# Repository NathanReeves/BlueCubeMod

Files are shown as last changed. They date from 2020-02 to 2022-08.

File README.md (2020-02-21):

# BlueCubeMod

ESP32 based GameCube Controller Bluetooth conversion for Nintendo Switch

v1:
Mac/PC/PS4 supported (tested using Dolphin Emulator on Mac, for Switch/RaspberryPi, use an 8Bitdo USB adapter)

v2: 
Switch support only - no adapter required

## Wiring:

- Connect pins 23 and 18 to GameCube controller's data pin (Red)

- Connect GND to controller's ground pin (Black)

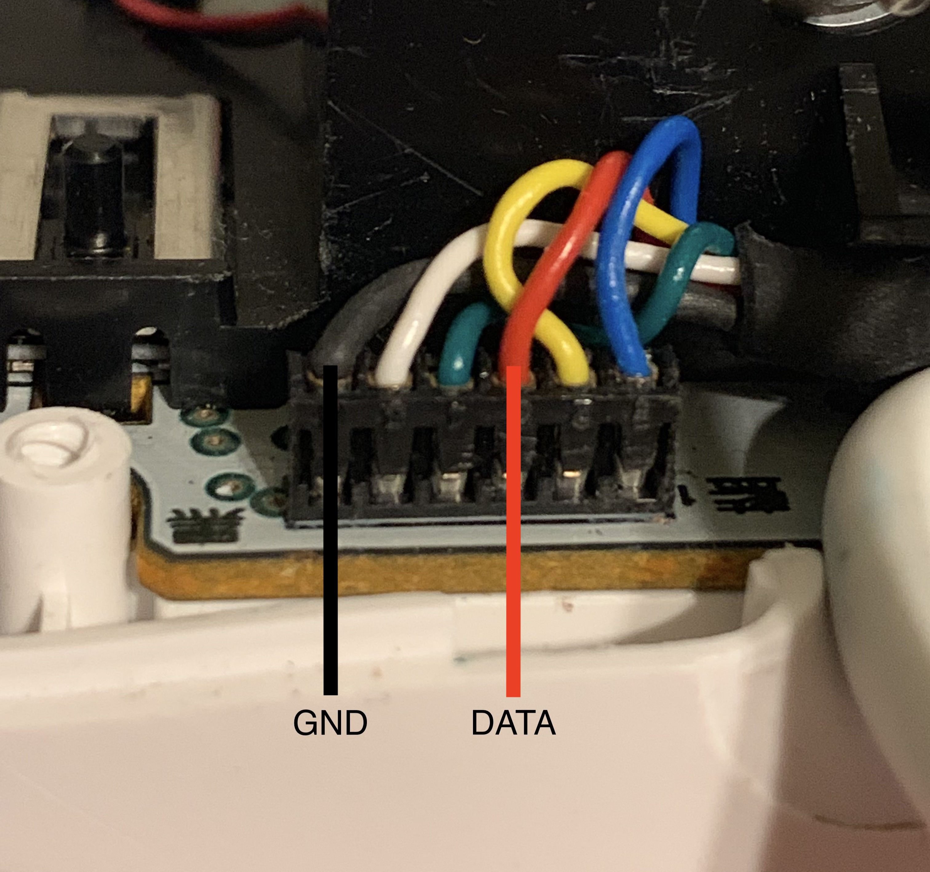
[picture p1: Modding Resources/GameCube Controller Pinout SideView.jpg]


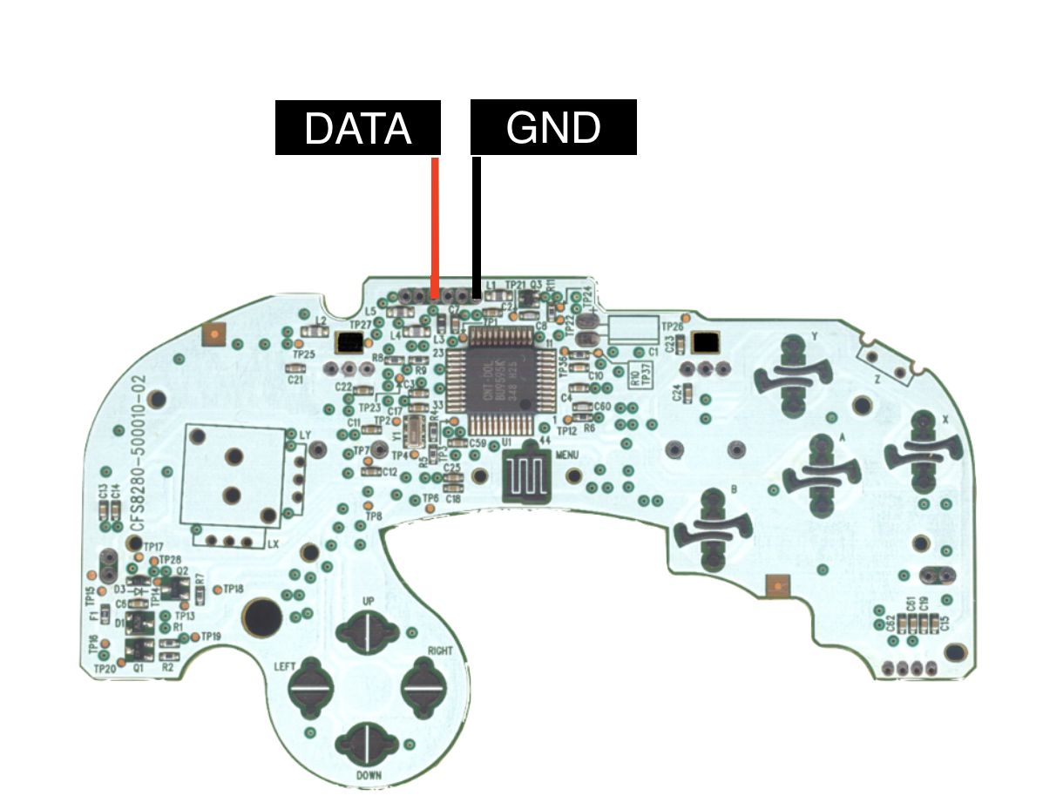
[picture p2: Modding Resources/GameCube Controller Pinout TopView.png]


## Build instructions(v2):

- Use this esp-idf fork here: https://github.com/NathanReeves/esp-idf

- Set up the esp-idf environment: https://docs.espressif.com/projects/esp-idf/en/latest/get-started/

- Get the BlueCubeModv2 firmware

- If you haven’t flashed an ESP32 project before, you need the port name of ESP32 for the config file. If using unix system, to get the port name of a USB device run:

`ls /dev`

- Find your device on the list and copy it. It should look something like: /dev/cu.usbserial-DO01EXOV or /dev/cu.SLAB_USBtoUART

- cd into project folder and run:

`make menuconfig`

- Paste your port name into Serial Flasher Config -> Default Serial Port

- Compile and flash the program, run:

`make flash monitor`

Resources used:

http://www.int03.co.uk/crema/hardware/gamecube/gc-control.htm

https://github.com/dekuNukem/Nintendo_Switch_Reverse_Engineering

https://github.com/timmeh87/switchnotes

Thank you to [@Molorius]( https://github.com/Molorius ) for implementing the bluedroid Classic stack for esp

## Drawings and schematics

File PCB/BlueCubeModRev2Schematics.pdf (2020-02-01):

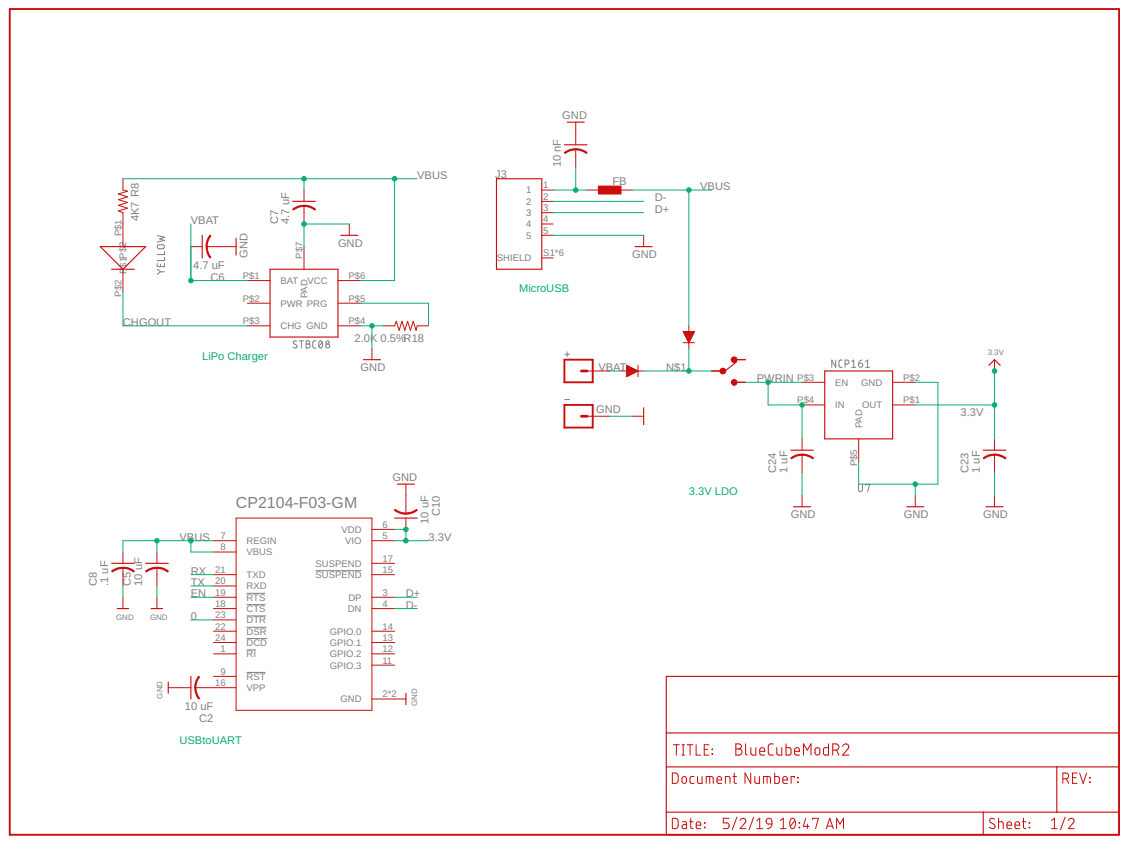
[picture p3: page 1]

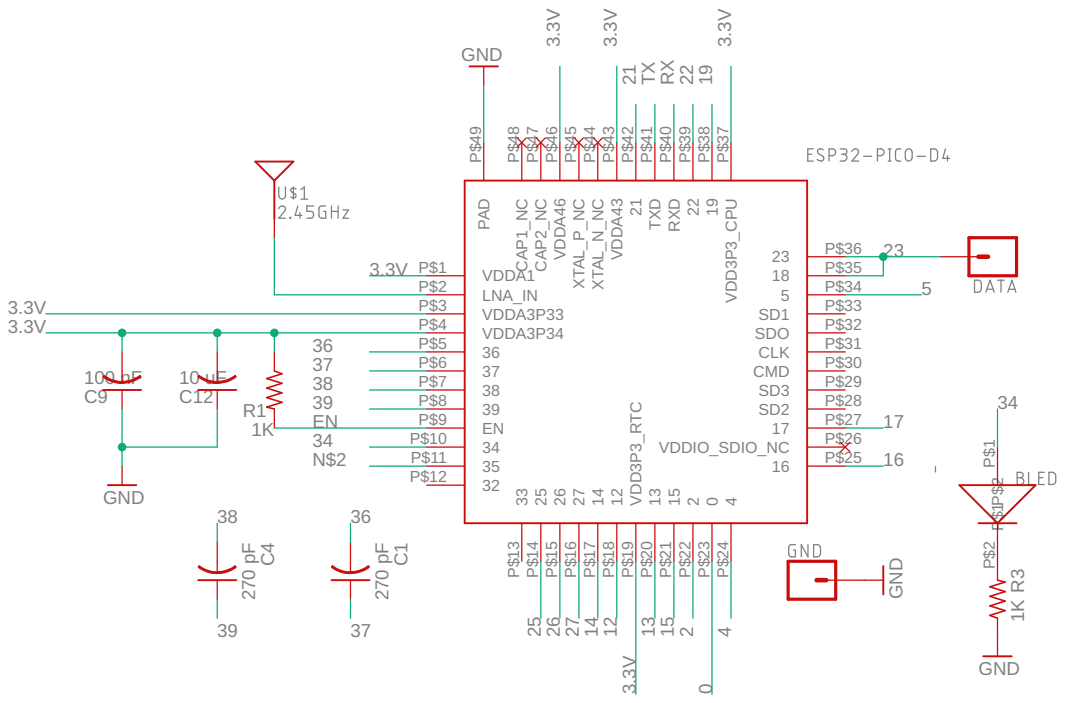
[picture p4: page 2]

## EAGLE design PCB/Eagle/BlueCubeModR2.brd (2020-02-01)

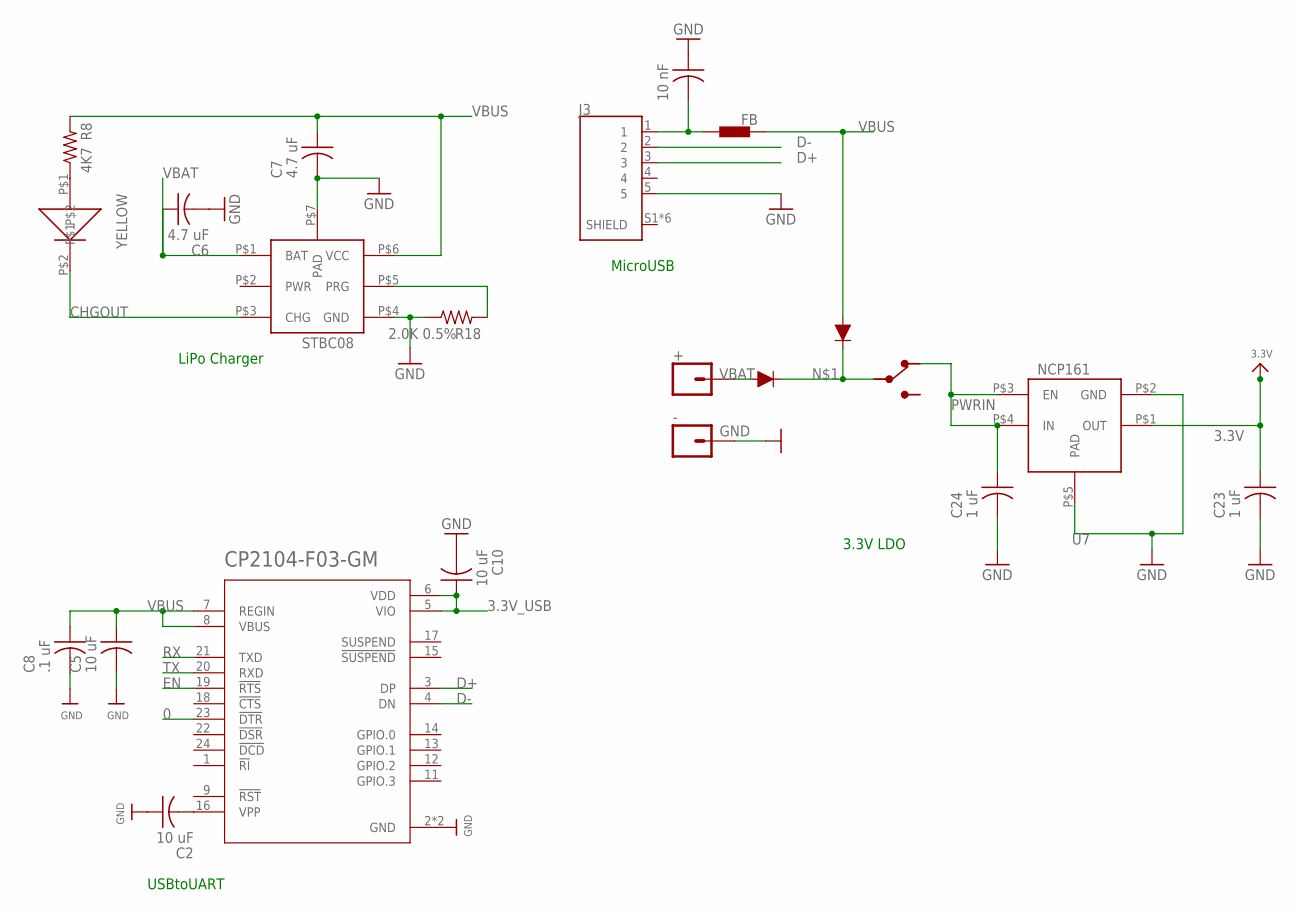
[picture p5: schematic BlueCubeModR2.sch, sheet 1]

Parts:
+: CONN_01; 1X01
-: CONN_01; 1X01
C2, C5, C10: 10 uF; C0402_B
C6, C7: 4.7 uF; C0402_B
C8: .1 uF; C0402_B
C11: 10 nF; C0402_B
C23, C24: 1 uF; C0402_B
J3: 2174507-2; J_SMD_2174507-2-5_7.8_5_2.71
L1: FB; 0402
R8: 4K7; R0402_B
R18: 2.0K 0.5%; R0402_B
S2: JS102011JCQN; SW_JS102011JCQN
U2: CP2104-F03-GM; QFN50P400X400X80-25N
U4: STBC08
U7: NCP161
U$4, U$5: DIODD3; DIODFN100X60X30-2
YELLOW: _; 0402LED

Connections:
0: U2.23 (!DTR); also elsewhere on the board
3.3V: C23.1, U7.P$1 (OUT); also elsewhere on the board
3.3V_USB: C10.1, U2.5 (VIO), U2.6 (VDD)
CHGOUT: U4.P$3 (CHG), YELLOW.P$2
D+: J3.3, U2.3 (DP)
D-: J3.2, U2.4 (DN)
EN: U2.19 (!RTS); also elsewhere on the board
GND: -.1, C2.1, C5.2, C6.2, C7.2, C8.2, C10.2, C11.1, C23.2, C24.2, J3.5, R18.1, U2.2 (GND), U2.25 (GND), U4.P$4 (GND), U4.P$7 (PAD), U7.P$2 (GND), U7.P$5 (PAD); also elsewhere on the board
unnamed: S2.2, U$4.2 (C), U$5.2 (C)
unnamed: R8.1, YELLOW.P$1
unnamed: C11.2, J3.1, L1.2
unnamed: C2.2, U2.16 (VPP)
unnamed: R18.2, U4.P$5 (PRG)
PWRIN: C24.1, S2.1, U7.P$3 (EN), U7.P$4 (IN)
RX: U2.21 (TXD); also elsewhere on the board
TX: U2.20 (RXD); also elsewhere on the board
VBAT: +.1, C6.1, U4.P$1 (BAT), U$4.1 (A)
VBUS: C5.1, C7.1, C8.1, L1.1, R8.2, U2.7 (REGIN), U2.8 (VBUS), U4.P$6 (VCC), U$5.1 (A)

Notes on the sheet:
MicroUSB
LiPo Charger
USBtoUART
3.3V LDO

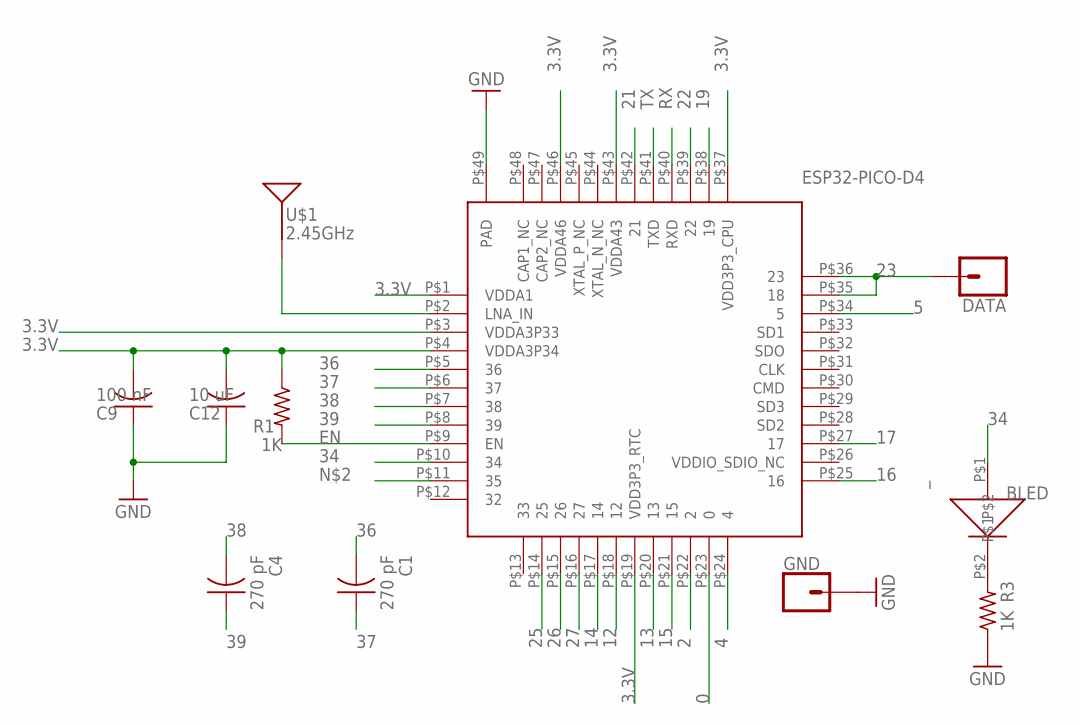
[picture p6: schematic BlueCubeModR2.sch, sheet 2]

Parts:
BLED: _; 0402LED
C1, C4: 270 pF; C0402_B
C9: 100 nF; C0402_B
C12: 10 uF; C0402_B
DATA: CONN_01; 1X01
GND: CONN_01; 1X01
R1, R3: 1K; R0402_B
U1: ESP32-PICO-D4
U$1: 2.45GHz; ANT-2.4GHZ-6.5X2.2MM

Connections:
0: U1.P$23 (0); also elsewhere on the board
2: U1.P$22 (2)
3.3V: C9.2, C12.2, R1.1, U1.P$1 (VDDA1), U1.P$3 (VDDA3P33), U1.P$4 (VDDA3P34), U1.P$19 (VDD3P3_RTC), U1.P$37 (VDD3P3_CPU), U1.P$43 (VDDA43), U1.P$46 (VDDA46); also elsewhere on the board
4: U1.P$24 (4)
5: U1.P$34 (5)
12: U1.P$18 (12)
13: U1.P$20 (13)
14: U1.P$17 (14)
15: U1.P$21 (15)
16: U1.P$25 (16)
17: U1.P$27 (17)
19: U1.P$38 (19)
21: U1.P$42 (21)
22: U1.P$39 (22)
23: DATA.1, U1.P$35 (18), U1.P$36 (23)
25: U1.P$14 (25)
26: U1.P$15 (26)
27: U1.P$16 (27)
34: BLED.P$1, U1.P$10 (34)
36: C1.2, U1.P$5 (36)
37: C1.1, U1.P$6 (37)
38: C4.2, U1.P$7 (38)
39: C4.1, U1.P$8 (39)
EN: R1.2, U1.P$9 (EN); also elsewhere on the board
ESPANT: U1.P$2 (LNA_IN), U$1.FEED
GND: C9.1, C12.1, GND.1, R3.1, U1.P$49 (PAD); also elsewhere on the board
unnamed: BLED.P$2, R3.2
RX: U1.P$40 (RXD); also elsewhere on the board
TX: U1.P$41 (TXD); also elsewhere on the board

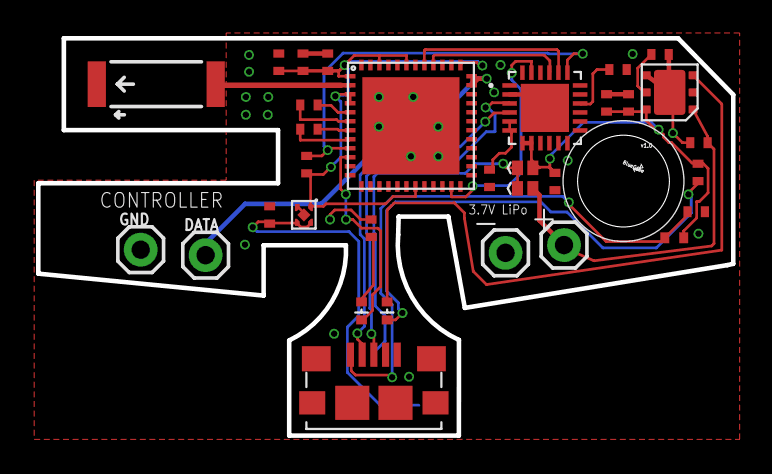
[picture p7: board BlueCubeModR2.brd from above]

Board: 4 copper layers, 38.6 x 22.1 mm, 33 parts (1 on the bottom side), 26 nets.

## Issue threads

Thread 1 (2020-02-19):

Compile Error

Caroma97, 2020-02-19:
Hi,

first of all, nice project :D
I love the old gamecube controller and it would be awesome if i could use it wireless on my switch.

But i have a problem while compiling the scipt:
[pastebin error log](https://pastebin.com/Bu83mwVP)

My system:
Windows 10 x64
esp32_win32_msys2_environment_and_gcc5_toolchain-20191220 (downloaded from the linked esppressif doc)
esp-idf: master branch from your linked fork

Maybe you know where my mistake is?
This is my first project with the esp, so please be patient. ^^

Greetings
Mario

NathanReeves, 2020-02-19:
Hey 👋
Thank you for finding this, I moved some things around and xSemaphore got declared later than it should have. I just pushed a commit to fix this.
Thanks again!
Have fun
-Nathan

Closed 2020-02-19.

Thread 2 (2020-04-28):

[Patch] Solution for Change Grip/Order menu closing

agustincampeny, 2020-04-28:
Hi!

I'm currently working on making an open source wireless SNES controller for the Switch, based on the ESP32 code that you wrote.

As the code already works really well, I'm trying to fix some things as to improve it.

I've managed to fix the Grip/Order menu closing by simply changing the length of the `report30` array in this chunk:

https://github.com/NathanReeves/BlueCubeMod/blob/3615f8f9732d90824d4daae8e04659d1dd8173f0/Firmware/BlueCubeModv2/main/main.c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

What I did was this:

```c
static uint8_t report30[49] = {
    [1] = 0x30,
    [2] = 0x0,
    [3] = 0x80,
    [13] = 0x08
};
```

I will try to notify you if I find other fixes to your code, If you're interested of course.

agustincampeny, 2020-04-28:
My fix was completely wrong. It definitely worked but because of the incorrect reasons.

The new `report30` array I made wasn't right because I put the first value in spot 1 instead of spot 0 (Matlab user), but this mistake solved the issue (but made the controller unusable). This made me realize that the problem was that the ESP was sending reports while pairing still wasn't ready, and this is what was closing the Grip/Order menu.

The definitive fix was to not send reports until pairing was complete. I modified this bit:

https://github.com/NathanReeves/BlueCubeMod/blob/3615f8f9732d90824d4daae8e04659d1dd8173f0/Firmware/BlueCubeModv2/main/main.c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

And changed it for this:

```c
if(timer == 255)
        timer = 0;
    //esp_hid_device_send_report(ESP_HIDD_REPORT_TYPE_INTRDATA, 0xa1, sizeof(report30), report30);

    if(!paired) {
        esp_hid_device_send_report(ESP_HIDD_REPORT_TYPE_INTRDATA, 0xa1, sizeof(dummy), dummy);
        vTaskDelay(100);
    }
    else {
        esp_hid_device_send_report(ESP_HIDD_REPORT_TYPE_INTRDATA, 0xa1, sizeof(report30), report30);
        vTaskDelay(15);
    }
```

Where dummy is a one element array with value 0.

NathanReeves, 2020-04-28:
Nice find! I was testing this last night, it seems to work better with the timer value in the dummy report too. Now we can connect other controllers without getting booted :)

Closed 2020-04-28.

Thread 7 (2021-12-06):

help with HID braille for open source devices for people with disabilities

discapacidad5, 2021-12-06:
help with HID braille for open source devices for people with disabilities

Hello, I am developing a device for people with disabilities. I need to use the HID braille protocol but I am not getting anything with HID for esp32, could you help me with a sample code of how I can implement the HID braille protocol?

here are references to braille HID

https://usb.org/sites/default/files/hutrr78_-_creation_of_a_braille_display_usage_page_0.pdf

https://github.com/nvaccess/nvda/blob/00cd67b737bc5b23a6f5e31cf28110b64ebf2fee/devDocs/hidBrailleTechnicalNotes.md

my repository is the following
https://github.com/brailletouch/Brailletouch

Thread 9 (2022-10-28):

Port To Arduino?

vin2890, 2022-10-28:
Anyway we can get this ported to Arduino to work, with an UNO/NANO etc? It would like to use your code to interface between a hardwired game cube controller and the switch, and to be able to remap buttons, use custom macros etc

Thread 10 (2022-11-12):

It doesn't work :(

I2000C, 2022-11-12:
Hi, I have compiled the project with latest esp-idf (v4.4.3), connected GPIO pins 18 and 23 to Gamecube controller DATA pin and connected GND pin to Gamecube controller GND pin.
However, the ESP32 isn't able to communicate with the Gamecube controller :(.
Besides, I have configured it to show the first 32 rmt_item32 items received.
These items are:

W (1316029) esp32: 0: 1 0 0 1
W (1316029) esp32: 1: 1 0 3 1
W (1316029) esp32: 2: 3 0 1 1
W (1316029) esp32: 3: 3 0 1 1
W (1316039) esp32: 4: 3 0 1 1
W (1316039) esp32: 5: 3 0 1 1
W (1316039) esp32: 6: 3 0 1 1
W (1316049) esp32: 7: 3 0 1 1
W (1316049) esp32: 8: 3 0 1 1
W (1316059) esp32: 9: 3 0 1 1
W (1316059) esp32: 10: 3 0 1 1
W (1316069) esp32: 11: 3 0 1 1
W (1316069) esp32: 12: 3 0 1 1
W (1316069) esp32: 13: 3 0 1 1
W (1316079) esp32: 14: 1 0 3 1
W (1316079) esp32: 15: 1 0 3 1
W (1316089) esp32: 16: 3 0 1 1
W (1316089) esp32: 17: 3 0 1 1
W (1316099) esp32: 18: 3 0 1 1
W (1316099) esp32: 19: 3 0 1 1
W (1316109) esp32: 20: 3 0 1 1
W (1316109) esp32: 21: 3 0 1 1
W (1316109) esp32: 22: 3 0 1 1
W (1316119) esp32: 23: 3 0 1 1
W (1316119) esp32: 24: 1 0 0 1
W (1316129) esp32: 25: 18934 1 27478 1
W (1316129) esp32: 26: 18397 1 3978 0
W (1316139) esp32: 27: 8344 0 23849 0
W (1316139) esp32: 28: 7315 0 25973 0
W (1316149) esp32: 29: 25632 1 24430 1
W (1316149) esp32: 30: 30681 1 12190 1
W (1316159) esp32: 31: 16434 0 19663 0

Please, could you help me?

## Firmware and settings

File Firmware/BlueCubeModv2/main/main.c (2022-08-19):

//
//  BlueCubeMod Firmware
//
//
//  Created by Nathan Reeves 2019
//
#include <stdio.h>
#include "sdkconfig.h"
#include "esp_spi_flash.h"

#include "esp_log.h"
#include "esp_hidd_api.h"
#include "esp_bt_main.h"
#include "esp_bt_device.h"
#include "esp_bt.h"
#include "esp_err.h"
#include "esp_system.h"
#include "nvs.h"
#include "nvs_flash.h"
#include "esp_gap_bt_api.h"
#include <string.h>
#include <inttypes.h>
#include <math.h>
#include "esp_timer.h"

#include "freertos/FreeRTOS.h"
#include "freertos/task.h"
#include "freertos/semphr.h"

#include "driver/gpio.h"
#include "driver/rmt.h"
#include "driver/periph_ctrl.h"
#include "soc/rmt_reg.h"



#define LED_GPIO    25
#define PIN_SEL  (1ULL<<LED_GPIO)

//for reading GameCube controller values
#define RMT_TX_GPIO_NUM  23     // GameCube TX GPIO ----
#define RMT_RX_GPIO_NUM  18     // GameCube RX GPIO ----
#define RMT_TX_CHANNEL    2     /*!< RMT channel for transmitter */
#define RMT_RX_CHANNEL    3     /*!< RMT channel for receiver */
#define RMT_CLK_DIV      80    /*!< RMT counter clock divider */
#define RMT_TICK_10_US    (80000000/RMT_CLK_DIV/100000)   /*!< RMT counter value for 10 us.(Source clock is APB clock) */
#define rmt_item32_tIMEOUT_US  9500   /*!< RMT receiver timeout value(us) */

//Calibration
static int lxcalib = 0;
static int lycalib = 0;
static int cxcalib = 0;
static int cycalib = 0;
static int lcalib = 0;
static int rcalib = 0;
//Buttons and sticks
static uint8_t but1_send = 0;
static uint8_t but2_send = 0;
static uint8_t but3_send = 0;
static uint8_t lx_send = 0;
static uint8_t ly_send = 0;
static uint8_t cx_send = 0;
static uint8_t cy_send = 0;
static uint8_t lt_send = 0;
static uint8_t rt_send = 0;


//static esp_hidd_callbacks_t callbacks;
static esp_hidd_app_param_t app_param;
static esp_hidd_qos_param_t both_qos;

//RMT Transmitter Init - for reading GameCube controller
rmt_item32_t items[25];
rmt_config_t rmt_tx;

SemaphoreHandle_t xSemaphore;
bool connected = false;
int paired = 0;
TaskHandle_t SendingHandle = NULL;
TaskHandle_t BlinkHandle = NULL;
uint8_t timer = 0;
static void rmt_tx_init()
{

        rmt_tx.channel = RMT_TX_CHANNEL;
        rmt_tx.gpio_num = RMT_TX_GPIO_NUM;
        rmt_tx.mem_block_num = 1;
        rmt_tx.clk_div = RMT_CLK_DIV;
        rmt_tx.tx_config.loop_en = false;
        rmt_tx.tx_config.carrier_freq_hz = 24000000;
        rmt_tx.tx_config.carrier_level = 1;
        rmt_tx.tx_config.carrier_en = 0;
        rmt_tx.tx_config.idle_level = 1;
        rmt_tx.tx_config.idle_output_en = true;
        rmt_tx.rmt_mode = 0;
        rmt_config(&rmt_tx);
        rmt_driver_install(rmt_tx.channel, 0, 0);

        //Fill items[] with console->controller command: 0100 0000 0000 0011 0000 0010

        items[0].duration0 = 3;
        items[0].level0 = 0;
        items[0].duration1 = 1;
        items[0].level1 = 1;
        items[1].duration0 = 1;
        items[1].level0 = 0;
        items[1].duration1 = 3;
        items[1].level1 = 1;
        int j;
        for(j = 0; j < 12; j++) {
                items[j+2].duration0 = 3;
                items[j+2].level0 = 0;
                items[j+2].duration1 = 1;
                items[j+2].level1 = 1;
        }
        items[14].duration0 = 1;
        items[14].level0 = 0;
        items[14].duration1 = 3;
        items[14].level1 = 1;
        items[15].duration0 = 1;
        items[15].level0 = 0;
        items[15].duration1 = 3;
        items[15].level1 = 1;
        for(j = 0; j < 8; j++) {
                items[j+16].duration0 = 3;
                items[j+16].level0 = 0;
                items[j+16].duration1 = 1;
                items[j+16].level1 = 1;
        }
        items[24].duration0 = 1;
        items[24].level0 = 0;
        items[24].duration1 = 3;
        items[24].level1 = 1;

}

//RMT Receiver Init
rmt_config_t rmt_rx;
static void rmt_rx_init()
{
        rmt_rx.channel = RMT_RX_CHANNEL;
        rmt_rx.gpio_num = RMT_RX_GPIO_NUM;
        rmt_rx.clk_div = RMT_CLK_DIV;
        rmt_rx.mem_block_num = 4;
        rmt_rx.rmt_mode = RMT_MODE_RX;
        rmt_rx.rx_config.idle_threshold = rmt_item32_tIMEOUT_US / 10 * (RMT_TICK_10_US);
        rmt_config(&rmt_rx);
}

//Polls controller and formats response
//GameCube Controller Protocol: http://www.int03.co.uk/crema/hardware/gamecube/gc-control.html
static void get_buttons()
{
        ESP_LOGI("hi", "Hello world from core %d!\n", xPortGetCoreID() );
        //button init values
        uint8_t but1 = 0;
        uint8_t but2 = 0;
        uint8_t but3 = 0;
        uint8_t dpad = 0x08;//Released
        uint8_t lx = 0;
        uint8_t ly = 0;
        uint8_t cx = 0;
        uint8_t cy = 0;
        uint8_t lt = 0;
        uint8_t rt = 0;

        //Sample and find calibration value for sticks
        int calib_loop = 0;
        int xsum = 0;
        int ysum = 0;
        int cxsum = 0;
        int cysum = 0;
        int lsum = 0;
        int rsum = 0;
        while(calib_loop < 5)
        {
                lx = 0;
                ly = 0;
                cx = 0;
                cy = 0;
                lt = 0;
                rt = 0;
                rmt_write_items(rmt_tx.channel, items, 25, 0);
                rmt_rx_start(rmt_rx.channel, 1);

                vTaskDelay(10);

                rmt_item32_t* item = (rmt_item32_t*) (RMT_CHANNEL_MEM(rmt_rx.channel));
                if(item[33].duration0 == 1 && item[27].duration0 == 1 && item[26].duration0 == 3 && item[25].duration0 == 3)
                {

                        //LEFT STICK X
                        for(int x = 8; x > -1; x--)
                        {
                                if((item[x+41].duration0 == 1))
                                {
                                        lx += pow(2, 8-x-1);
                                }
                        }

                        //LEFT STICK Y
                        for(int x = 8; x > -1; x--)
                        {
                                if((item[x+49].duration0 == 1))
                                {
                                        ly += pow(2, 8-x-1);
                                }
                        }
                        //C STICK X
                        for(int x = 8; x > -1; x--)
                        {
                                if((item[x+57].duration0 == 1))
                                {
                                        cx += pow(2, 8-x-1);
                                }
                        }

                        //C STICK Y
                        for(int x = 8; x > -1; x--)
                        {
                                if((item[x+65].duration0 == 1))
                                {
                                        cy += pow(2, 8-x-1);
                                }
                        }

                        //R AN
                        for(int x = 8; x > -1; x--)
                        {
                                if((item[x+73].duration0 == 1))
                                {
                                        rt += pow(2, 8-x-1);
                                }
                        }

                        //L AN
                        for(int x = 8; x > -1; x--)
                        {
                                if((item[x+81].duration0 == 1))
                                {
                                        lt += pow(2, 8-x-1);
                                }
                        }

                        xsum += lx;
                        ysum += ly;
                        cxsum += cx;
                        cysum += cy;
                        lsum += lt;
                        rsum += rt;
                        calib_loop++;
                }

        }

        //Set Stick Calibration
        lxcalib = 127-(xsum/5);
        lycalib = 127-(ysum/5);
        cxcalib = 127-(cxsum/5);
        cycalib = 127-(cysum/5);
        lcalib = 127-(lsum/5);
        rcalib = 127-(rsum/5);


        while(1)
        {
                but1 = 0;
                but2 = 0;
                but3 = 0;
                dpad = 0x08;
                lx = 0;
                ly = 0;
                cx = 0;
                cy = 0;
                lt = 0;
                rt = 0;

                //Write command to controller
                rmt_write_items(rmt_tx.channel, items, 25, 0);
                rmt_rx_start(rmt_rx.channel, 1);

                vTaskDelay(6); //6ms between sample

                rmt_item32_t* item = (rmt_item32_t*) (RMT_CHANNEL_MEM(rmt_rx.channel));

                //Check first 3 bits and high bit at index 33
                if(item[33].duration0 == 1 && item[27].duration0 == 1 && item[26].duration0 == 3 && item[25].duration0 == 3)
                {

                        //Button report: first item is item[25]
                        //0 0 1 S Y X B A
                        //1 L R Z U D R L
                        //Joystick X (8bit)
                        //Joystick Y (8bit)
                        //C-Stick X (8bit)
                        //C-Stick Y (8bit)
                        //L Trigger Analog (8/4bit)
                        //R Trigger Analog (8/4bit)

                        if(item[32].duration0 == 1) but1 += 0x08; // A
                        if(item[31].duration0 == 1) but1 += 0x04; // B
                        if(item[30].duration0 == 1) but1 += 0x02; // X
                        if(item[29].duration0 == 1) but1 += 0x01; // Y

                        if(item[28].duration0 == 1) but2 += 0x02; // START/PLUS

                        //DPAD
                        if(item[40].duration0 == 1) but3 += 0x08; // L
                        if(item[39].duration0 == 1) but3 += 0x04; // R
                        if(item[38].duration0 == 1) but3 += 0x01; // D
                        if(item[37].duration0 == 1) but3 += 0x02; // U

                        if(item[35].duration0 == 1) but1 += 0x80; // ZR
                        if(item[34].duration0 == 1) but3 += 0x80; // ZL
                        //Buttons
                        if(item[36].duration0 == 1)
                        {
                                but1 += 0x40;// Z
                                // if(but3 == 0x80) { but3 += 0x40;}
                                if(but2 == 0x02) { but2 = 0x01; } // Minus =  Z + Start
                                if(but3 == 0x02) { but2 = 0x10; } // Home =  Z + Up
                        }

                        //LEFT STICK X
                        for(int x = 8; x > -1; x--)
                        {
                                if(item[x+41].duration0 == 1)
                                {
                                        lx += pow(2, 8-x-1);
                                }
                        }

                        //LEFT STICK Y
                        for(int x = 8; x > -1; x--)
                        {
                                if(item[x+49].duration0 == 1)
                                {
                                        ly += pow(2, 8-x-1);
                                }
                        }

                        //C STICK X
                        for(int x = 8; x > -1; x--)
                        {
                                if(item[x+57].duration0 == 1)
                                {
                                        cx += pow(2, 8-x-1);
                                }
                        }

                        //C STICK Y
                        for(int x = 8; x > -1; x--)
                        {
                                if(item[x+65].duration0 == 1)
                                {
                                        cy += pow(2, 8-x-1);
                                }
                        }

                        /// Analog triggers here --  Ignore for Switch :/
                        /*
                           //R AN
                           for(int x = 8; x > -1; x--)
                           {
                            if(item[x+73].duration0 == 1)
                            {
                                rt += pow(2, 8-x-1);
                            }
                           }

                           //L AN
                           for(int x = 8; x > -1; x--)
                           {
                            if(item[x+81].duration0 == 1)
                            {
                                lt += pow(2, 8-x-1);
                            }
                           }*/
                        /////
                        but1_send = but1;
                        but2_send = but2;
                        but3_send = but3;
                        lx_send = lx + lxcalib;
                        ly_send = ly + lycalib;
                        cx_send = cx + cxcalib;
                        cy_send = cy + cycalib;
                        lt_send = 0;//lt;//left trigger analog
                        rt_send = 0;//rt;//right trigger analog
                }else{
                        //log_info("GameCube controller read fail");
                }

        }
}

//Switch button report example //         batlvl       Buttons              Lstick           Rstick
//static uint8_t report30[] = {0x30, 0x00, 0x90,   0x00, 0x00, 0x00,   0x00, 0x00, 0x00,   0x00, 0x00, 0x00};
static uint8_t report30[] = {
        0x30,
        0x0,
        0x80,
        0,//but1
        0,//but2
        0,//but3
        0,//Ls
        0,//Ls
        0,//Ls
        0,//Rs
        0,//Rs
        0,//Rs
        0x08
};
static uint8_t emptyReport[] = {
        0x0,
        0x0
};

void send_buttons()
{
        // // test
        // if(but1_send == 0)
        //         but1_send = 0x02; // X
        // else
        //         but1_send = 0;

        xSemaphoreTake(xSemaphore, portMAX_DELAY);
        report30[1] = timer;
        //buttons
        report30[3] = but1_send;
        report30[4] = but2_send;
        report30[5] = but3_send;
        //encode left stick
        report30[6] = (lx_send << 4) & 0xF0;
        report30[7] = (lx_send & 0xF0) >> 4;
        report30[8] = ly_send;
        //encode right stick
        report30[9] = (cx_send << 4) & 0xF0;
        report30[10] = (cx_send & 0xF0) >> 4;
        report30[11] = cy_send;
        xSemaphoreGive(xSemaphore);
        timer+=1;
        if(timer == 255)
                timer = 0;

        if(!paired)
        {
                emptyReport[1] = timer;
                esp_bt_hid_device_send_report(ESP_HIDD_REPORT_TYPE_INTRDATA, 0xa1, sizeof(emptyReport), emptyReport);
                vTaskDelay(100);
        }
        else
        {
                esp_bt_hid_device_send_report(ESP_HIDD_REPORT_TYPE_INTRDATA, 0xa1, sizeof(report30), report30);
                vTaskDelay(15);
        }


}
const uint8_t hid_descriptor_gamecube[] = {
        0x05, 0x01,    // Usage Page (Generic Desktop Ctrls)
        0x09, 0x05,    // Usage (Game Pad)
        0xA1, 0x01,    // Collection (Application)
        //Padding
        0x95, 0x03,      //     REPORT_COUNT = 3
        0x75, 0x08,      //     REPORT_SIZE = 8
        0x81, 0x03,      //     INPUT = Cnst,Var,Abs
        //Sticks
        0x09, 0x30,    //   Usage (X)
        0x09, 0x31,    //   Usage (Y)
        0x09, 0x32,    //   Usage (Z)
        0x09, 0x35,    //   Usage (Rz)
        0x15, 0x00,    //   Logical Minimum (0)
        0x26, 0xFF, 0x00, //   Logical Maximum (255)
        0x75, 0x08,    //   Report Size (8)
        0x95, 0x04,    //   Report Count (4)
        0x81, 0x02,    //   Input (Data,Var,Abs,No Wrap,Linear,Preferred State,No Null Position)
        //DPAD
        0x09, 0x39,    //   Usage (Hat switch)
        0x15, 0x00,    //   Logical Minimum (0)
        0x25, 0x07,    //   Logical Maximum (7)
        0x35, 0x00,    //   Physical Minimum (0)
        0x46, 0x3B, 0x01, //   Physical Maximum (315)
        0x65, 0x14,    //   Unit (System: English Rotation, Length: Centimeter)
        0x75, 0x04,    //   Report Size (4)
        0x95, 0x01,    //   Report Count (1)
        0x81, 0x42,    //   Input (Data,Var,Abs,No Wrap,Linear,Preferred State,Null State)
        //Buttons
        0x65, 0x00,    //   Unit (None)
        0x05, 0x09,    //   Usage Page (Button)
        0x19, 0x01,    //   Usage Minimum (0x01)
        0x29, 0x0E,    //   Usage Maximum (0x0E)
        0x15, 0x00,    //   Logical Minimum (0)
        0x25, 0x01,    //   Logical Maximum (1)
        0x75, 0x01,    //   Report Size (1)
        0x95, 0x0E,    //   Report Count (14)
        0x81, 0x02,    //   Input (Data,Var,Abs,No Wrap,Linear,Preferred State,No Null Position)
        //Padding
        0x06, 0x00, 0xFF, //   Usage Page (Vendor Defined 0xFF00)
        0x09, 0x20,    //   Usage (0x20)
        0x75, 0x06,    //   Report Size (6)
        0x95, 0x01,    //   Report Count (1)
        0x15, 0x00,    //   Logical Minimum (0)
        0x25, 0x7F,    //   Logical Maximum (127)
        0x81, 0x02,    //   Input (Data,Var,Abs,No Wrap,Linear,Preferred State,No Null Position)
        //Triggers
        0x05, 0x01,    //   Usage Page (Generic Desktop Ctrls)
        0x09, 0x33,    //   Usage (Rx)
        0x09, 0x34,    //   Usage (Ry)
        0x15, 0x00,    //   Logical Minimum (0)
        0x26, 0xFF, 0x00, //   Logical Maximum (255)
        0x75, 0x08,    //   Report Size (8)
        0x95, 0x02,    //   Report Count (2)
        0x81, 0x02,
        0xc0
};
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
void app_main(void)
{
        //GameCube Contoller reading init
        rmt_tx_init();
        rmt_rx_init();
        xTaskCreatePinnedToCore(get_buttons, "gbuttons", 2048, NULL, 1, NULL, 1);
        //flash LED
        vTaskDelay(100);
        gpio_set_level(LED_GPIO, 0);
        vTaskDelay(100);
        gpio_set_level(LED_GPIO, 1);
        vTaskDelay(100);
        gpio_set_level(LED_GPIO, 0);
        vTaskDelay(100);
        gpio_set_level(LED_GPIO, 1);
        vTaskDelay(100);
        gpio_set_level(LED_GPIO, 0);
        const char* TAG = "app_main";
        esp_err_t ret;

        xSemaphore = xSemaphoreCreateMutex();

        gpio_config_t io_conf;
        //disable interrupt
        io_conf.intr_type = GPIO_PIN_INTR_DISABLE;
        //set as output mode
        io_conf.mode = GPIO_MODE_OUTPUT;
        //bit mask of the pins that you want to set,e.g.GPIO18/19
        io_conf.pin_bit_mask = PIN_SEL;
        //disable pull-down mode
        io_conf.pull_down_en = 0;
        //disable pull-up mode
        io_conf.pull_up_en = 0;
        //configure GPIO with the given settings
        gpio_config(&io_conf);

        app_param.name = "BlueCubeMod";
        app_param.description = "BlueCubeMod Example";
        app_param.provider = "ESP32";
        app_param.subclass = 0x8;
        app_param.desc_list = hid_descriptor_gamecube;
        app_param.desc_list_len = hid_descriptor_gc_len;
        memset(&both_qos, 0, sizeof(esp_hidd_qos_param_t));

        ret = nvs_flash_init();
        if (ret == ESP_ERR_NVS_NO_FREE_PAGES || ret == ESP_ERR_NVS_NEW_VERSION_FOUND) {
                ESP_ERROR_CHECK(nvs_flash_erase());
                ret = nvs_flash_init();
        }
        ESP_ERROR_CHECK( ret );

        set_bt_address();

        ESP_ERROR_CHECK(esp_bt_controller_mem_release(ESP_BT_MODE_BLE));

        esp_bt_controller_config_t bt_cfg = BT_CONTROLLER_INIT_CONFIG_DEFAULT();
        esp_bt_mem_release(ESP_BT_MODE_BLE);
        if ((ret = esp_bt_controller_init(&bt_cfg)) != ESP_OK) {
                ESP_LOGE(TAG, "initialize controller failed: %s\n",  esp_err_to_name(ret));
                return;
        }

        if ((ret = esp_bt_controller_enable(ESP_BT_MODE_CLASSIC_BT)) != ESP_OK) {
                ESP_LOGE(TAG, "enable controller failed: %s\n",  esp_err_to_name(ret));
                return;
        }

        if ((ret = esp_bluedroid_init()) != ESP_OK) {
                ESP_LOGE(TAG, "initialize bluedroid failed: %s\n",  esp_err_to_name(ret));
                return;
        }

        if ((ret = esp_bluedroid_enable()) != ESP_OK) {
                ESP_LOGE(TAG, "enable bluedroid failed: %s\n",  esp_err_to_name(ret));
                return;
        }

        if ((ret = esp_bt_gap_register_callback(esp_bt_gap_cb)) != ESP_OK) {
                ESP_LOGE(TAG, "gap register failed: %s\n", esp_err_to_name(ret));
                return;
        }

        ESP_LOGI(TAG, "setting device name");
        esp_bt_dev_set_device_name("Pro Controller");

        ESP_LOGI(TAG, "setting cod major, Pro Controller");
        esp_bt_cod_t cod;
        cod.major = 0x05;
        cod.minor = 0b0000010;
        esp_bt_gap_set_cod(cod,ESP_BT_SET_COD_MAJOR_MINOR     );

        vTaskDelay(2000 / portTICK_PERIOD_MS);

        ESP_LOGI(TAG, "register hid device callback");
        esp_bt_hid_device_register_callback(esp_bt_hidd_cb);

        ESP_LOGI(TAG, "starting hid device");
        esp_bt_hid_device_init();

        //start blinking
        xTaskCreate(startBlink, "blink_task", 1024, NULL, 1, &BlinkHandle);

        print_bt_address();
}

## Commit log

2019-05-02 added board files
    [BlueCubeModR2.brd, BlueCubeModR2.sch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]
2020-02-01 Added v2 firmware w/ switch support
    see updated readme for new build instructions
    [BlueCubeModR2.brd, BlueCubeModR2.sch]
2020-04-29 store a random mac address in flash
    Allows multiple controllers on one switch console
2020-04-29 put random bt addr in switch packet
2021-11-27 fixed v2 firmware to work using latest esp_idf
    [main.c]

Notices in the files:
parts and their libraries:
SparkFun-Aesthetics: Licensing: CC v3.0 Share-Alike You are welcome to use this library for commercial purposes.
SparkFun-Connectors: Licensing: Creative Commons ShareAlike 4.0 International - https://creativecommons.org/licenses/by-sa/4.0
